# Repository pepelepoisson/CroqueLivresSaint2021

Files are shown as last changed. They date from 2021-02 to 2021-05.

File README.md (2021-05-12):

***
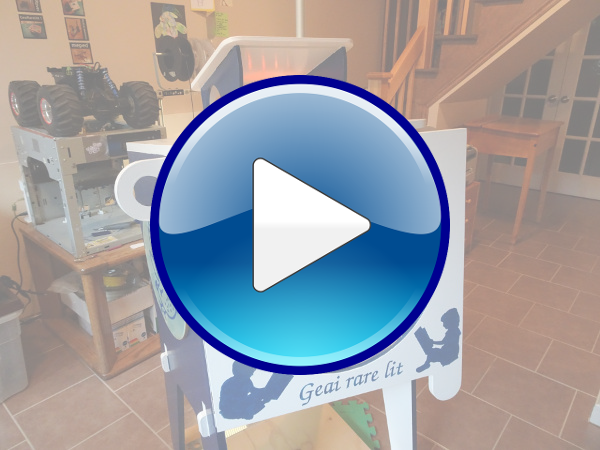
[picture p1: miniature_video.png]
Project video (https://youtu.be/Az-vB4r0-Qg)

***
This repo contains files about a project called GeaiRareLit. It is all about building a small ESP8266 brain for a little bookcase installed outside of my local school. The device is solar powered and drives WS2812B leds + epaper when door is opened. ePaper is used to display an inspiring sentence from a famous author. Users passing by the bookself get the chance to read the sentence even tough they have no book to give or take. All project details are available on the [project page](http://www.chezpapietmamie.com/pcube/uncategorized/geairarelit/)
***
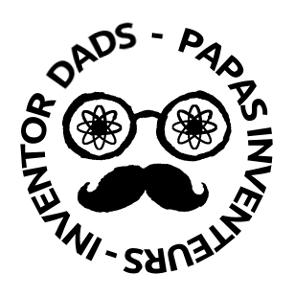
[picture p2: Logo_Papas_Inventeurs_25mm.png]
Inventor Dads logo


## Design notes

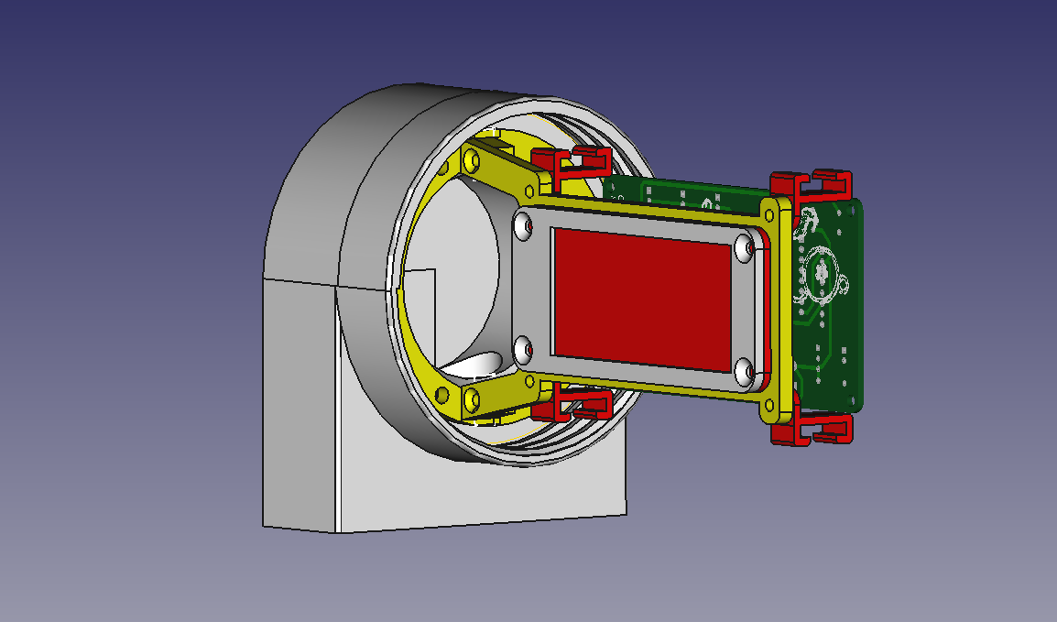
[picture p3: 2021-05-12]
CAD/concept2-3.png

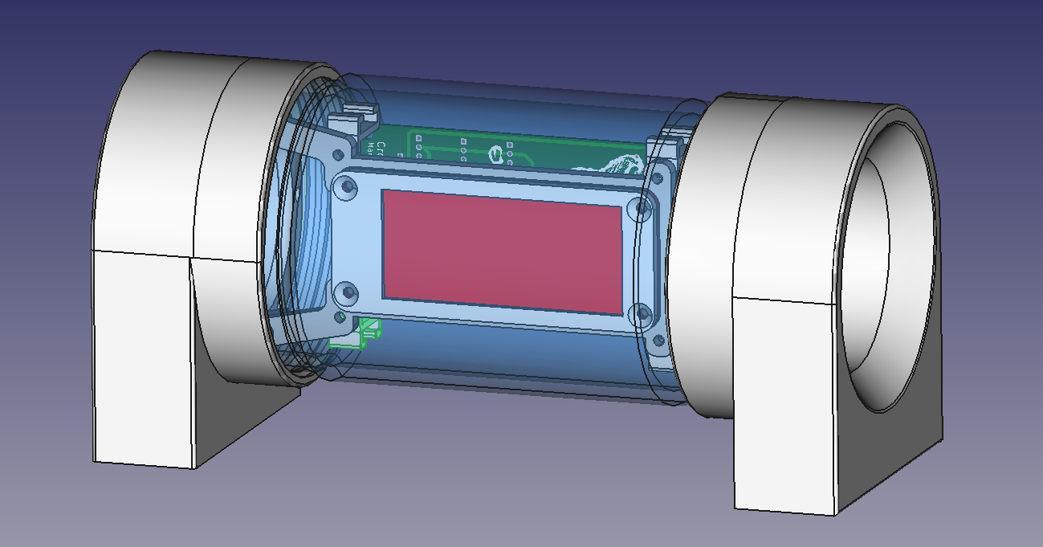
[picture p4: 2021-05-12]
CAD/concept2-1.png

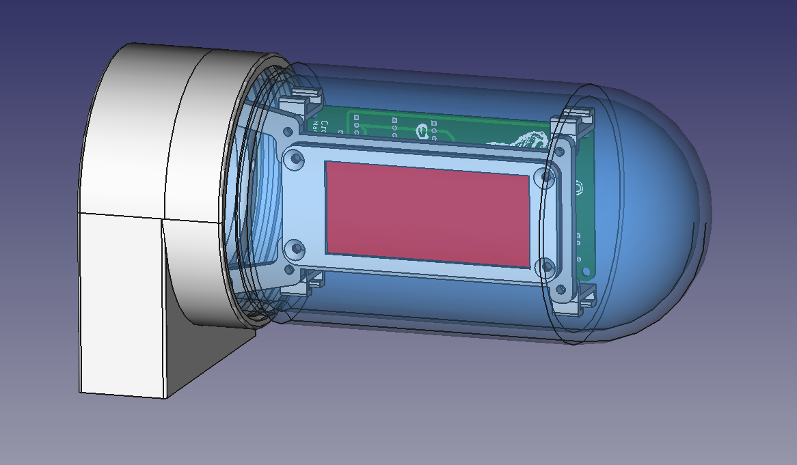
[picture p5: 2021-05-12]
CAD/concept2-2.png

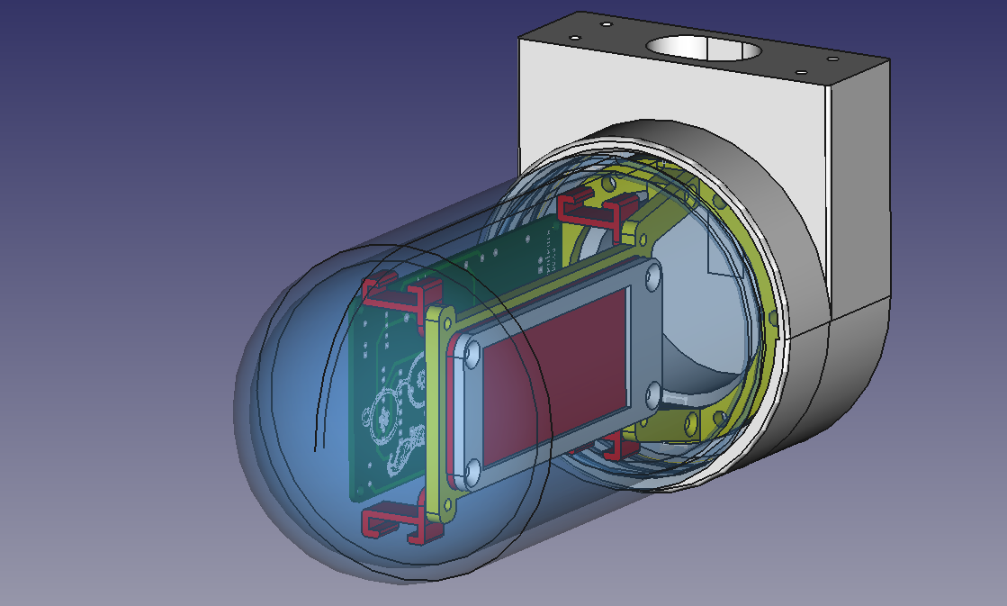
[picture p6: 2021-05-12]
CAD/concept2-4.png

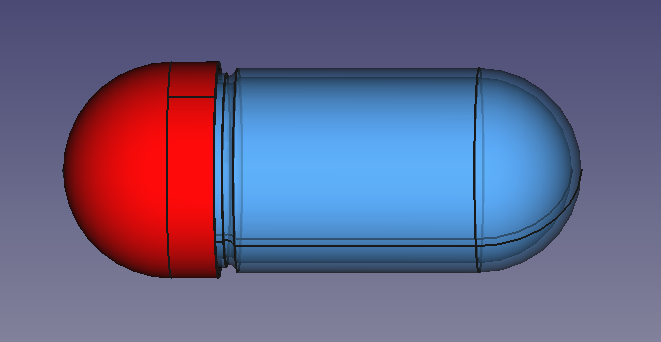
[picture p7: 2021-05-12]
CAD/concept1.png

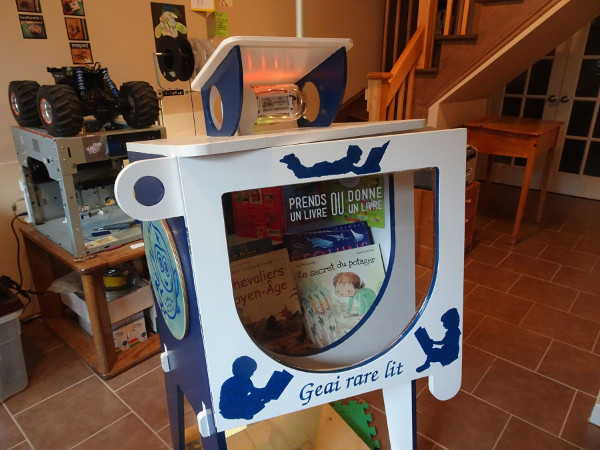
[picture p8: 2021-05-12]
miniature.png

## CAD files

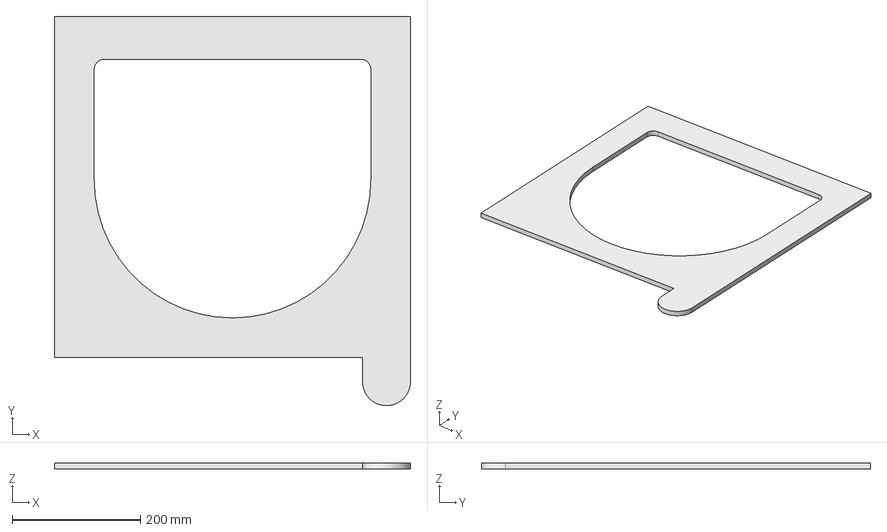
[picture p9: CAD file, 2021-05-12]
CAD/CNC/porte.FCStd
556.0 x 608.0 x 10.0 mm

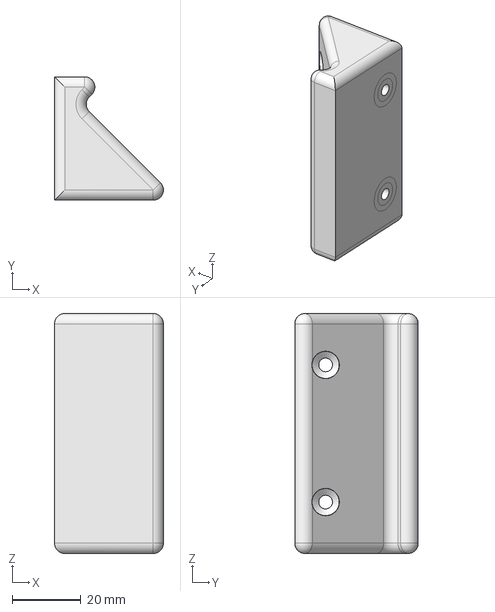
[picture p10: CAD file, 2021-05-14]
CAD/Poignée_V1.FCStd
31.8 x 36.0 x 70.0 mm

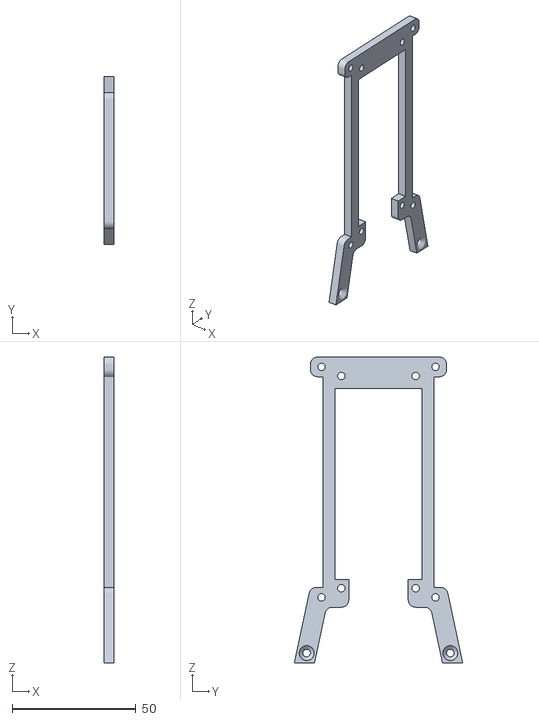
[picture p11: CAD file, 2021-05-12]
CAD/CrocSaintGerard_V5-support_plaque_ecran_V1.stl
4.00 x 68.0 x 123.5

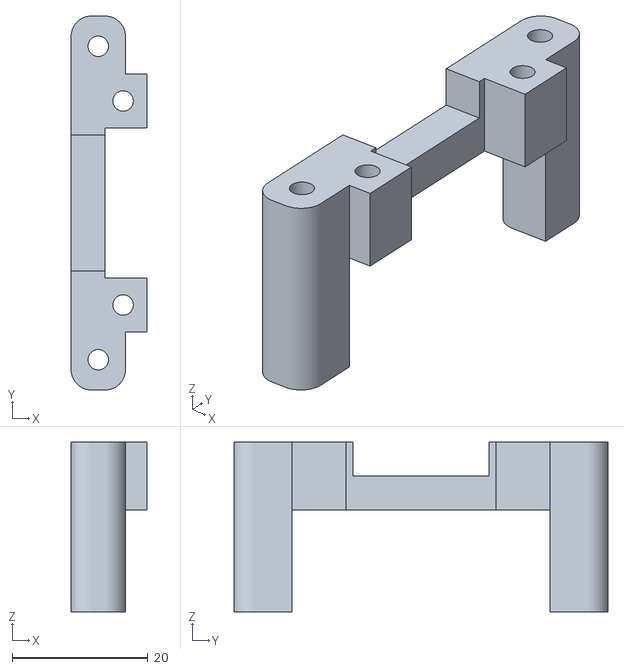
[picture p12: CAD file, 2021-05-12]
CAD/Montage_ecran_PCB_V2.stl
11.2 x 55.0 x 25.0

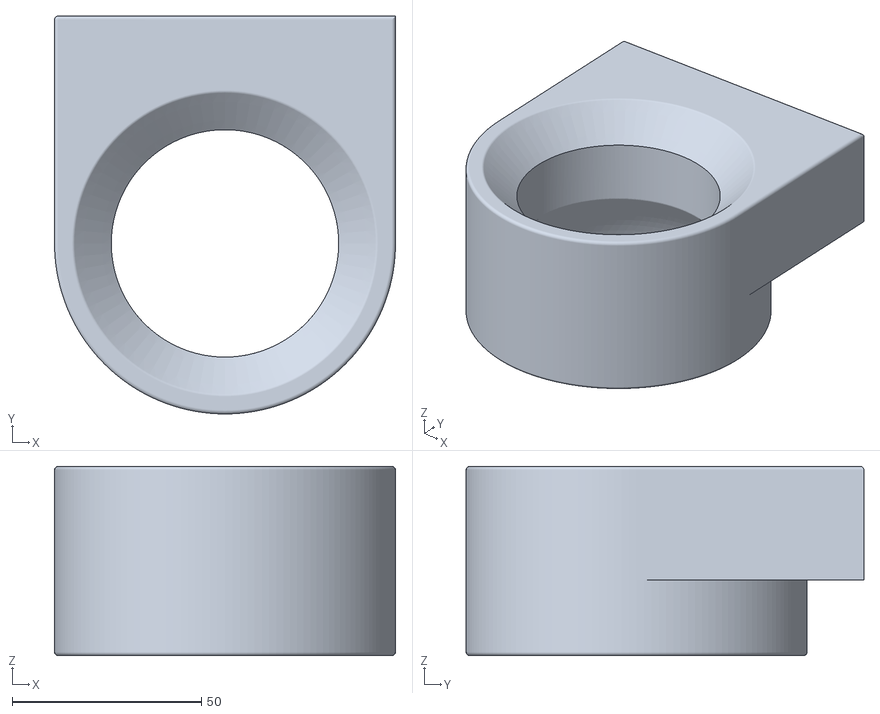
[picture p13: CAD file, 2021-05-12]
CAD/CrocSaintGerard_V4-tete_V1.stl
90.0 x 105.0 x 50.0

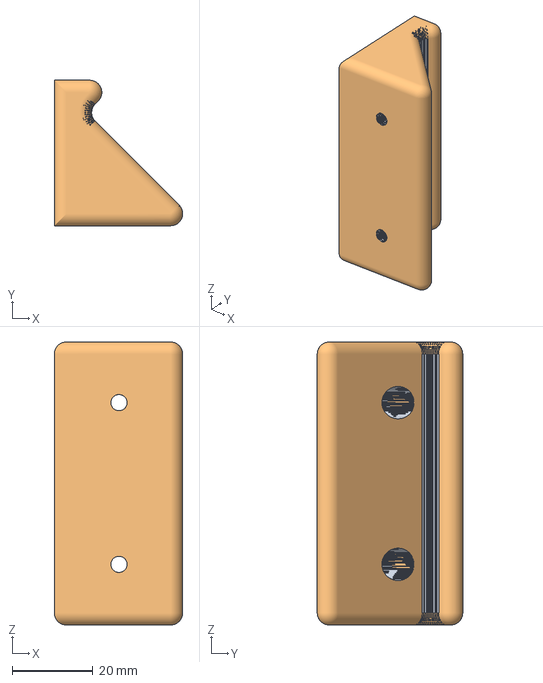
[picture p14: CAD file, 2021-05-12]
CAD/Butée_V1.FCStd
31.8 x 36.0 x 70.0 mm
Poignée
Poignée (Meshed)

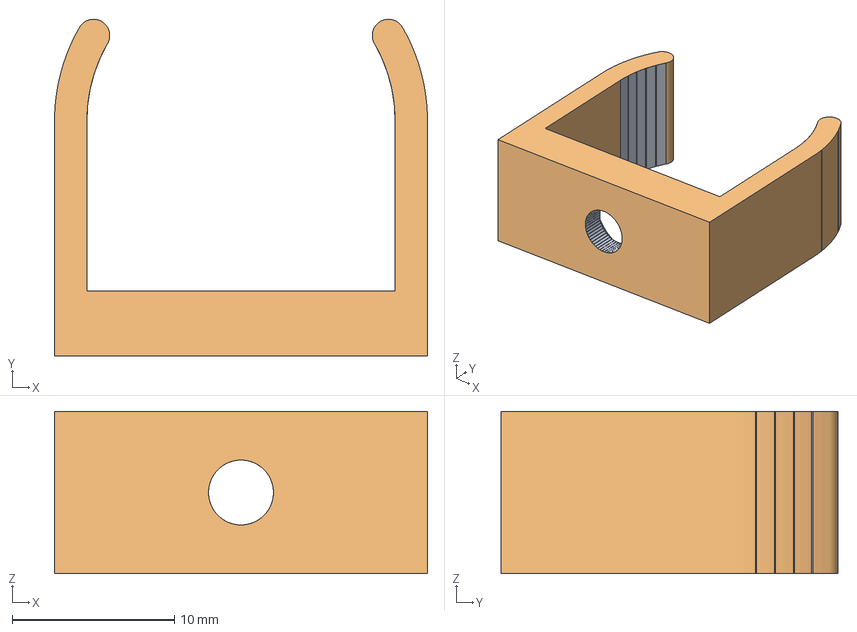
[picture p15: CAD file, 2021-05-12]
CAD/Support_batterie_V1.FCStd
23.0 x 20.8 x 10.0 mm
Body (Meshed)

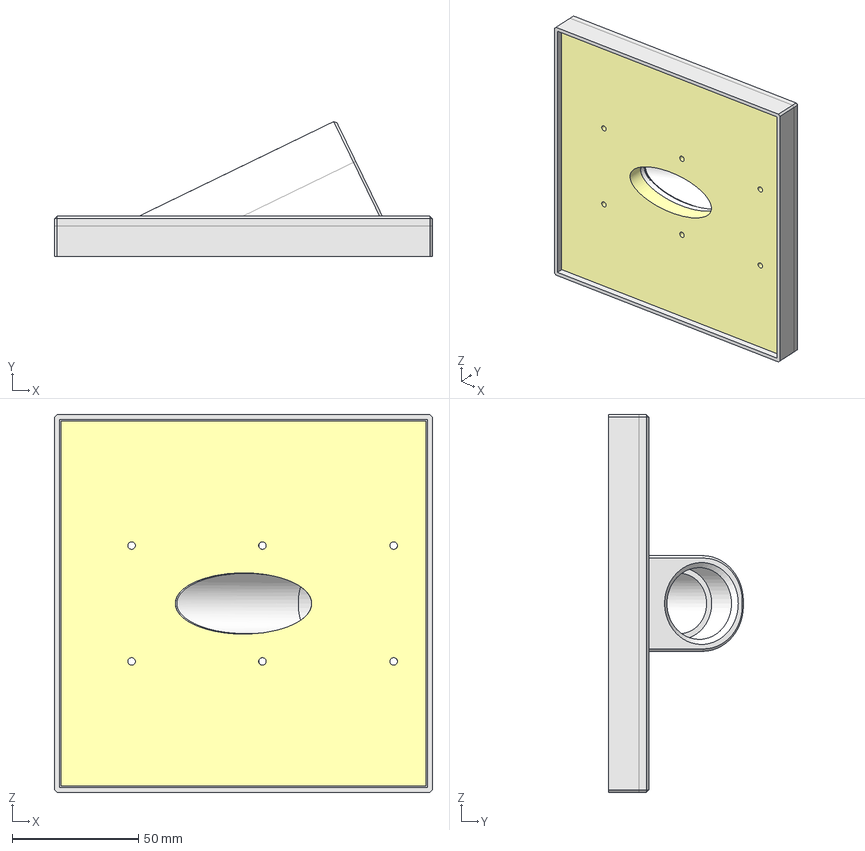
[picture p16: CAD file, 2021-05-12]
CAD/support_panneau_solaire_haut.FCStd
150.0 x 53.5 x 150.0 mm
fixation_mat
Contour
base_carree

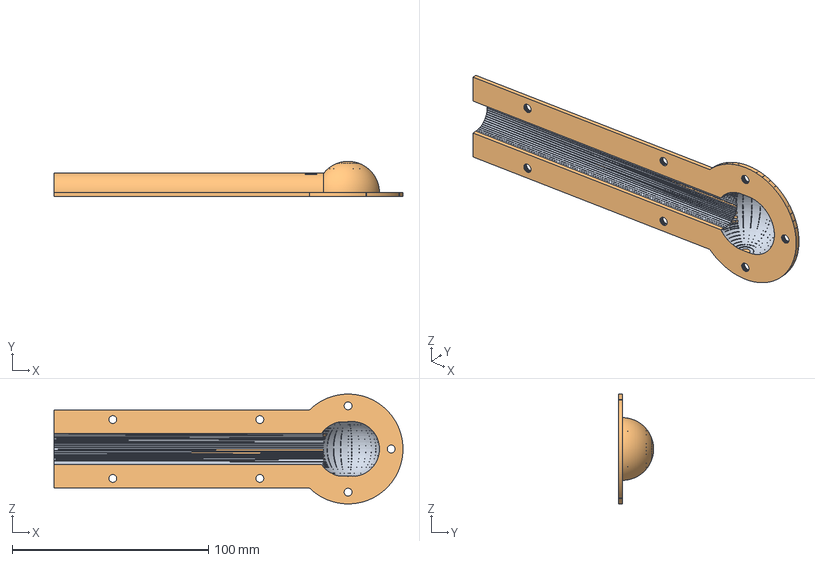
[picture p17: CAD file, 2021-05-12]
CAD/cache_fils_V1.FCStd
178.0 x 18.0 x 56.0 mm
Body (Meshed)

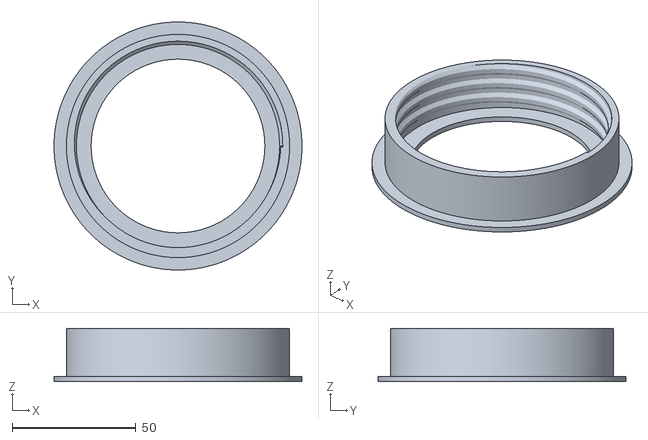
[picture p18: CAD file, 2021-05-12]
CAD/Test_base_vis_V1.stl
100.0 x 100.0 x 21.5

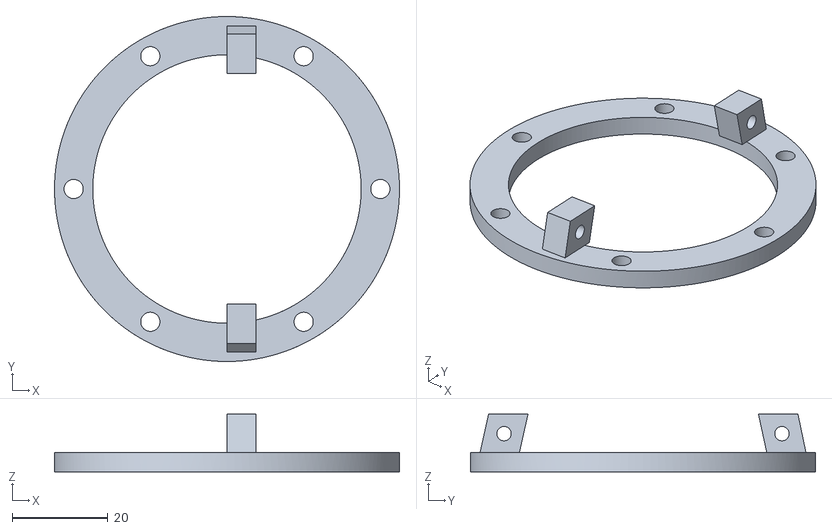
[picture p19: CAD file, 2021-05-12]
CAD/CrocSaintGerard_V5-fixation_support_plaque_ecran_V1.stl
72.0 x 72.0 x 12.0

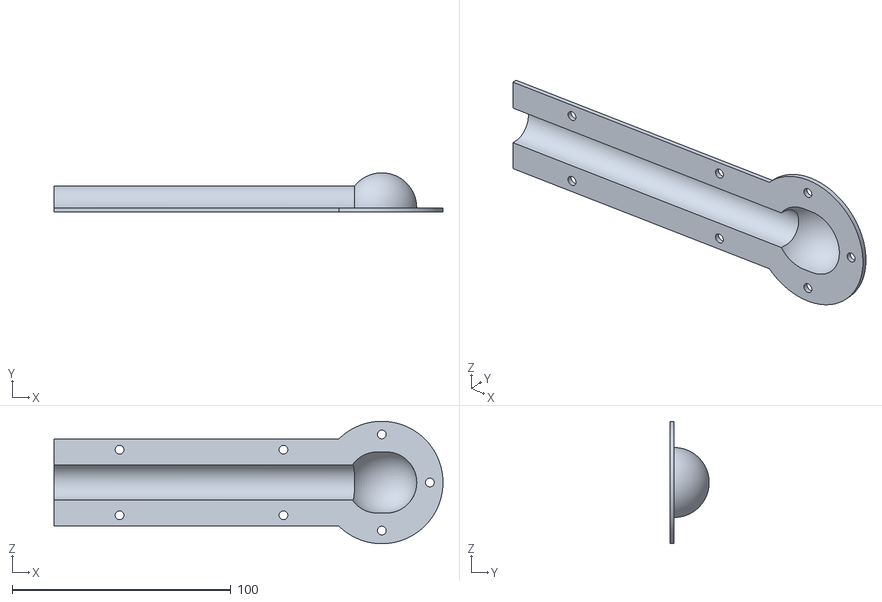
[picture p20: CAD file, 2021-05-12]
CAD/cache_fils_V1_V1.stl
178.0 x 18.0 x 56.0

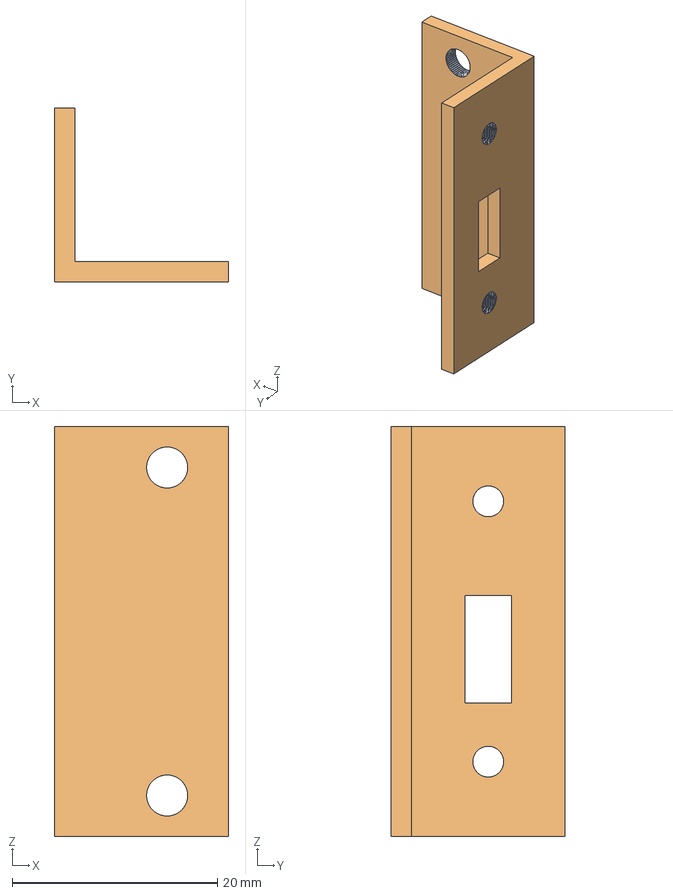
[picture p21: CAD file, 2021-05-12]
CAD/Support_interrupteur_V1.FCStd
17.0 x 17.0 x 40.0 mm
Support_unterrupteur
Support_unterrupteur (Meshed)

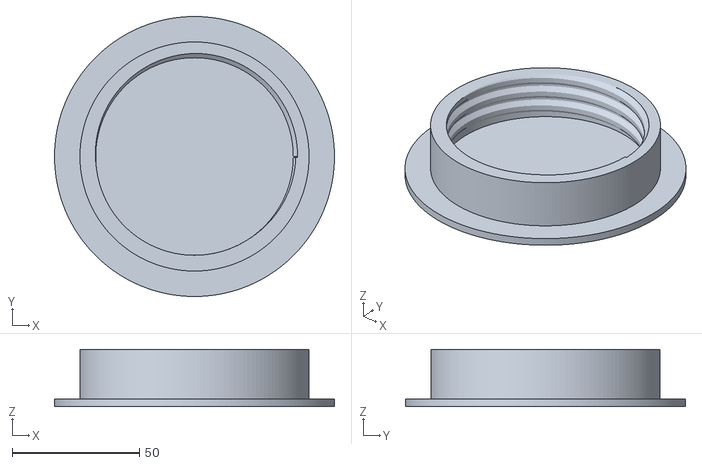
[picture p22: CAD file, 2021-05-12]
CAD/Vis-Body (Meshed).stl
110.0 x 110.0 x 22.5

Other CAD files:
CAD/Assemblage_PCB_ecran.FCStd
CAD/CrocSaintGerard.FCStd
CAD/Poignée_V1_V1.stl
CAD/CrocSaintGerard_V6.FCStd
CAD/Butée_V1.stl
CAD/CrocSaintGerard_V2.FCStd
CAD/CrocSaintGerard_V3-fixation_enceinte_verre_V1.stl
CAD/CrocSaintGerard_V3-tete_V1.stl
CAD/CrocSaintGerard_V3.FCStd
CAD/CrocSaintGerard_V4.FCStd
CAD/CrocSaintGerard_V5-attache_leds_V1.stl
CAD/CrocSaintGerard_V5.FCStd
CAD/Montage_ecran_PCB_V1.stl
CAD/Support_batterie_V1.stl
CAD/Support_interrupteur_V1.stl
CAD/Vis.FCStd
CAD/support_panneau_solaire_haut_Contour_V1.stl
CAD/support_panneau_solaire_haut_V1.stl

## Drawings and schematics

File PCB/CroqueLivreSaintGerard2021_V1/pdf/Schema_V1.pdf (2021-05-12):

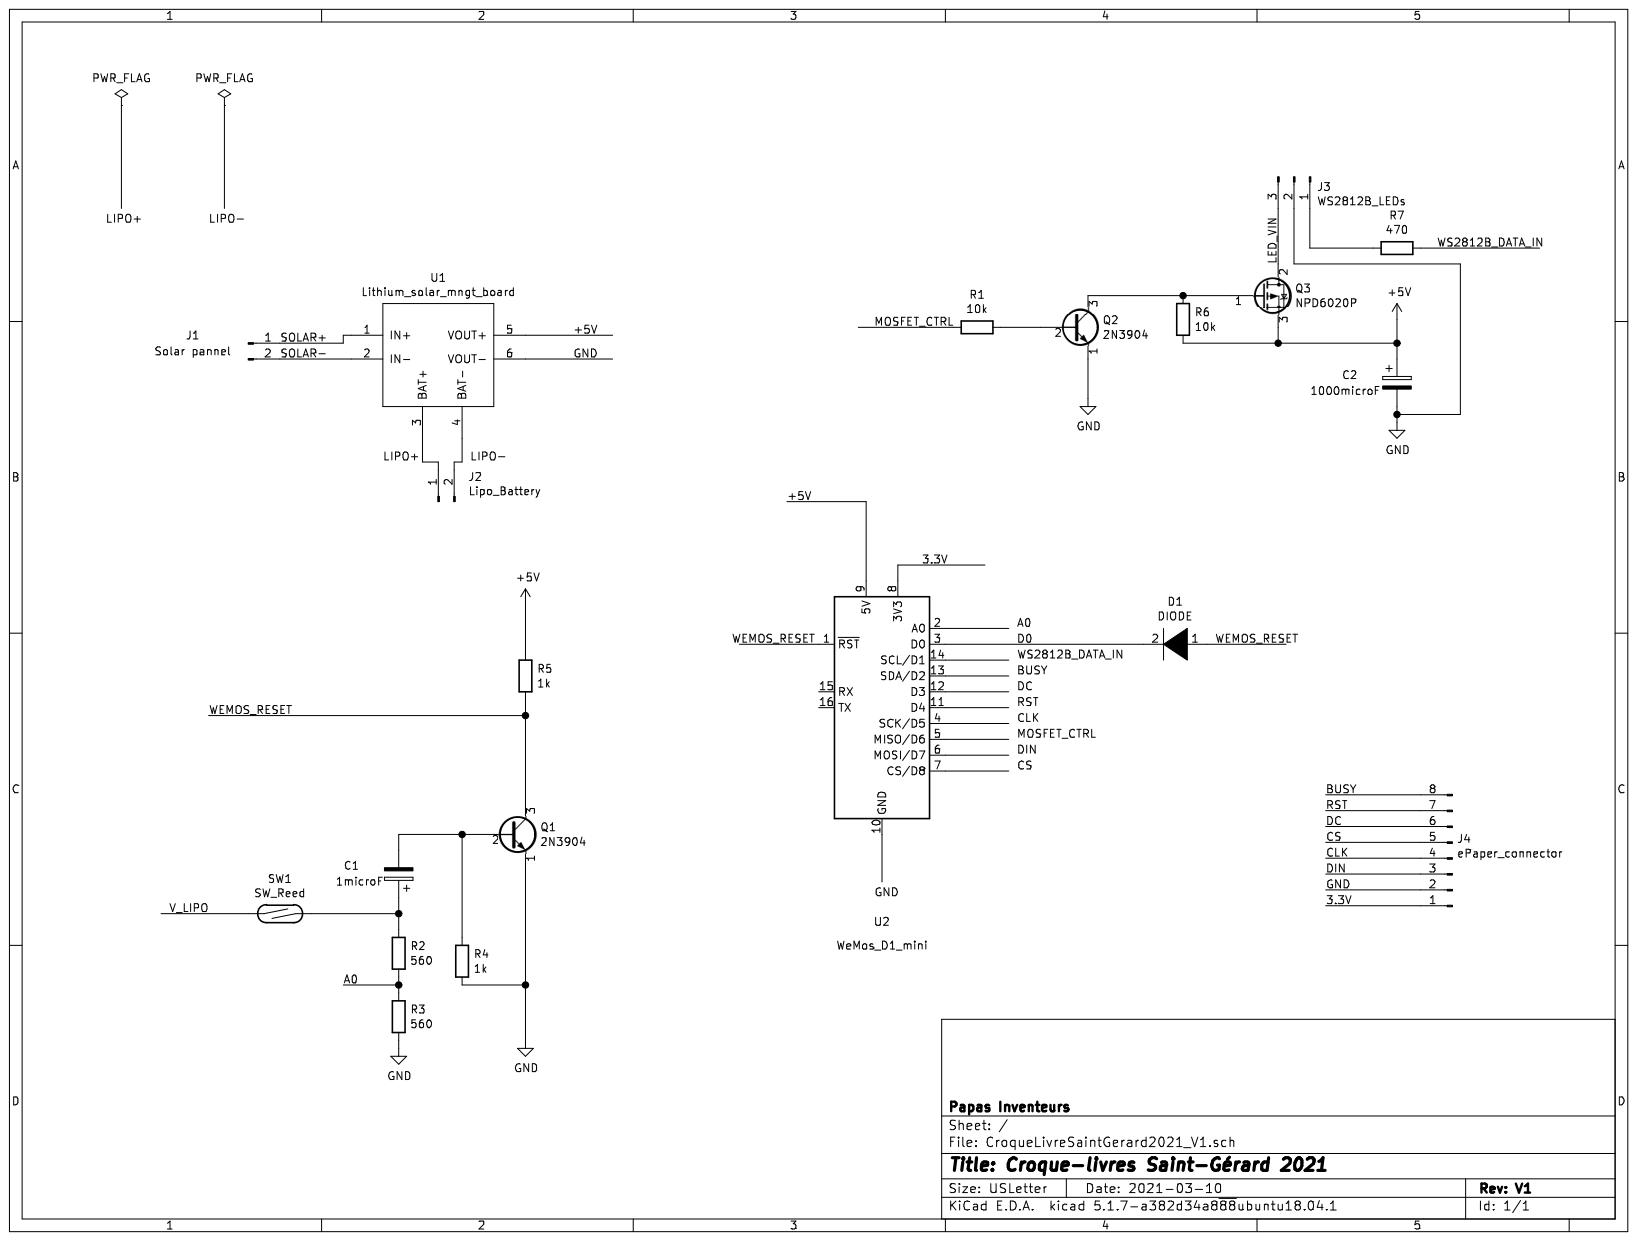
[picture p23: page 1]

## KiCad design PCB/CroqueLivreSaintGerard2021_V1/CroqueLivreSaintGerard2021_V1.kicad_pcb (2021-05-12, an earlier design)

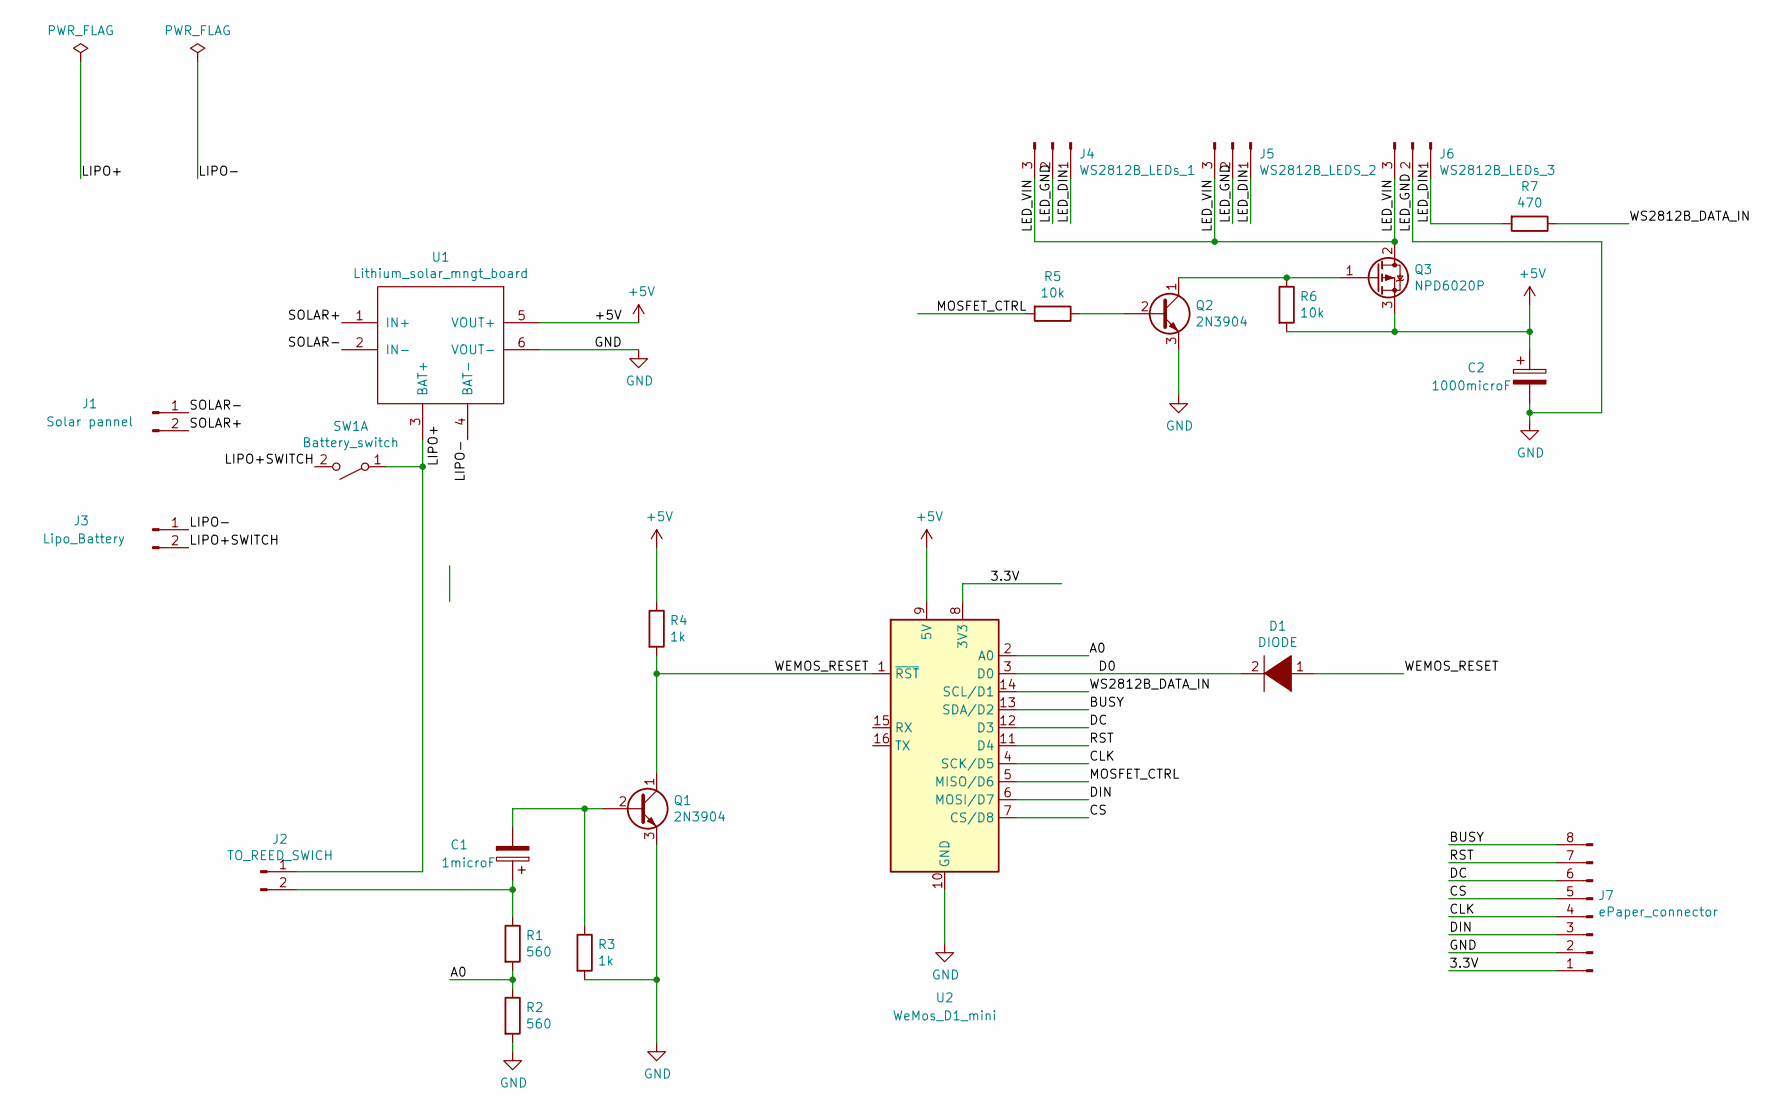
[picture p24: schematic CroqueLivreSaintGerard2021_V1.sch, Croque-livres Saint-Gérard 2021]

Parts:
C1: 1microF; CP_Radial_D6.3mm_P2.50mm
C2: 1000microF; Edge_CP_Radial_D12.5mm_P5.00mm
D1: DIODE; D_DO-41_SOD81_P10.16mm_Horizontal
J1: Solar pannel; JST_EH_S2B-EH_1x02_P2.50mm_Horizontal
J2: TO_REED_SWICH; PinHeader_1x02_P2.54mm_Horizontal
J3: Lipo_Battery; JST_EH_S2B-EH_1x02_P2.50mm_Horizontal
J4: WS2812B_LEDs_1; PinHeader_1x03_P2.54mm_Vertical
J5: WS2812B_LEDS_2; PinHeader_1x03_P2.54mm_Vertical
J6: WS2812B_LEDs_3; PinHeader_1x03_P2.54mm_Vertical
J7: ePaper_connector; PinSocket_1x08_P2.54mm_Horizontal
Q1, Q2: 2N3904; TO-92L_Inline_Wide
Q3: NPD6020P; TO-220-3_Horizontal_TabDown
R1, R2: 560; R_Axial_DIN0207_L6.3mm_D2.5mm_P10.16mm_Horizontal
R3, R4: 1k; R_Axial_DIN0207_L6.3mm_D2.5mm_P10.16mm_Horizontal
R5, R6: 10k; R_Axial_DIN0207_L6.3mm_D2.5mm_P10.16mm_Horizontal
R7: 470; R_Axial_DIN0207_L6.3mm_D2.5mm_P10.16mm_Horizontal
SW1: Battery_switch; SW_Slide_1P2T_CK_OS102011MS2Q
U1: Lithium_solar_mngt_board
U2: WeMos_D1_mini; WEMOS_D1_mini_light

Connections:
+5V: C2.1, Q3.3 (S), R4.1, R6.2, U1.5 (VOUT+), U2.9 (5V)
/3.3V: J7.1, U2.8 (3V3)
/A0: R1.2, R2.1, U2.2 (A0)
/BUSY: J7.8, U2.13 (SDA/D2)
/CLK: J7.4, U2.4 (SCK/D5)
/CS: J7.5, U2.7 (CS/D8)
/D0: D1.2 (A), U2.3 (D0)
/DC: J7.6, U2.12 (D3)
/DIN: J7.3, U2.6 (MOSI/D7)
/LED_DIN: J4.1, J5.1, J6.1, R7.2
/LED_VIN: J4.3, J5.3, J6.3, Q3.2 (D)
/LIPO+SWITCH: J3.2, SW1.2 (B); also elsewhere on the board
/LIPO-: J3.1, U1.4 (BAT-); also elsewhere on the board
/MOSFET_CTRL: R5.2, U2.5 (MISO/D6)
/RST: J7.7, U2.11 (D4)
/SOLAR+: J1.2, U1.1 (IN+); also elsewhere on the board
/SOLAR-: J1.1, U1.2 (IN-); also elsewhere on the board
/WEMOS_RESET: D1.1 (K), Q1.1 (C), R4.2, U2.1 (~RST)
/WS2812B_DATA_IN: R7.1, U2.14 (SCL/D1)
GND: C2.2, J4.2, J5.2, J6.2, J7.2, Q1.3 (E), Q2.3 (E), R2.2, R3.2, U1.6 (VOUT-), U2.10 (GND)
unnamed: C1.1, J2.2, R1.1
unnamed: C1.2, Q1.2 (B), R3.1
unnamed: J2.1, SW1.1 (A), U1.3 (BAT+)
unnamed: Q2.1 (C), Q3.1 (G), R6.1
unnamed: Q2.2 (B), R5.1

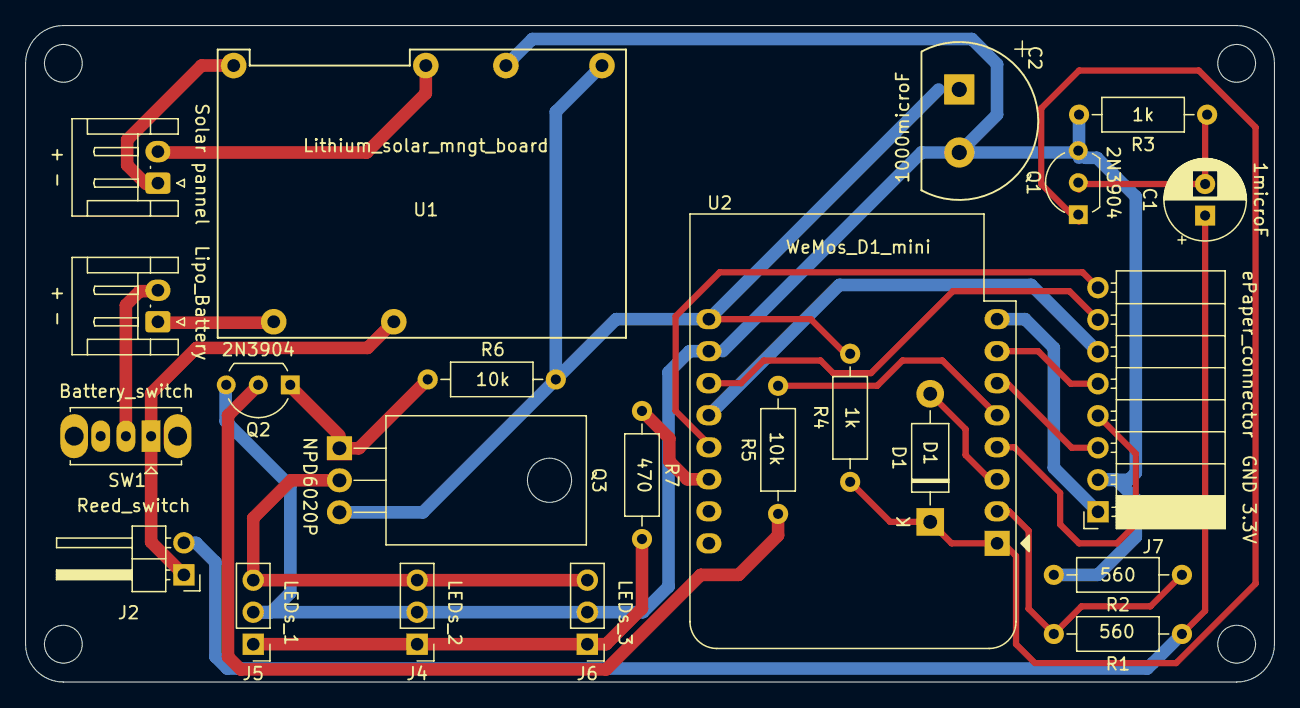
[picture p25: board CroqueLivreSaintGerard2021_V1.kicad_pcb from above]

Board: 2 copper layers, 99.1 x 52.1 mm, 24 parts (1 on the bottom side), 25 nets.

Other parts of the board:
+ -: Lipo_Battery; JST_EH_S2B-EH_1x02_P2.50mm_Horizontal
+ -#2: Solar pannel; JST_EH_S2B-EH_1x02_P2.50mm_Horizontal
LOGO_papas_inventeurs_et_jeunes: LOGO_papas_inventeurs_et_jeunes (72x48mm)

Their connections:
/LIPO+SWITCH: + -.2; also elsewhere on the board
/LIPO-: + -.1; also elsewhere on the board
/SOLAR+: + -#2.2; also elsewhere on the board
/SOLAR-: + -#2.1; also elsewhere on the board

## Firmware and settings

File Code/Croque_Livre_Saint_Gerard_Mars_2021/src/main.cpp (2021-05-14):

// To do:
// Change deco leds to be displayed on 9 and 30 LEDs strips
// Wifi mode: only start wifi access is door is closed less than 3 seconds after opening
// Fix citation counter disply and avoid showing a blank screen at the end of the sequence

// Done - now in trial mode:
// Code to handle access point and station mode wifi
// Store number of code execution in persistent memory
// Handle new epaper type
// Handle reading different text content at every execution
// Improve wake-up hardware and detect when door is open
// Control duration of LED animatins and sleep start based on door status
// Must handle errors when reading log file gives no valid number
// Allow use of international characters when printing text (accents)
// Measure battery level
// Add end of line characters as needed to prevent words from cutting at the end of lines when text is displayed on epaper.

// Main examples used to build this secondes
// Basic SPIFFS write/read example: https://github.com/G6EJD/SPIFFS-Examples/blob/master/ESP8266_SPIFFS_Example.ino
// Uploading a file to SPIFFS from browser: https://www.esp8266.com/viewtopic.php?t=5779&start=10#

// Wonderfull online true type to gfx fonts conversion tool: https://rop.nl/truetype2gfx/
// Wonderfull online tool to edit fonts: https://tchapi.github.io/Adafruit-GFX-Font-Customiser/

#include <Arduino.h>
#include <GxEPD2.h>
#include <Adafruit_GFX.h>
#include <Adafruit_I2CDevice.h>
#include <ESP8266WiFi.h>
#include <WiFiClient.h>
#include <ESP8266WebServer.h>
#include <Adafruit_NeoPixel.h>
#include <FS.h> //spiff file system
#include <ArduinoJson.h>

#define ARRAY_SIZE(A) (sizeof(A) / sizeof((A)[0]))
#define LOW_BRIGHTNESS          20
#define FRAMES_PER_SECOND   60 // 125 frames/sec <=> 8 milli/frame
#define NUM_LEDS  30
#define DATA_PIN    5
#define MOSFET_GATE  12
#define LED_ANIMATIONS_DURATION 60000 // Duration of LED animations (Milliseconds)

Adafruit_NeoPixel strip = Adafruit_NeoPixel(NUM_LEDS, DATA_PIN, NEO_GRB + NEO_KHZ800);
uint8_t gCurrentPatternNumber = 0; // Index number of which pattern is current
uint16_t brightness=LOW_BRIGHTNESS;
long start_time=0;
int updated_code_run_counter=0;
int updated_current_citation=0;
int number_of_citations=0;
bool doorOpen=false;
bool citations_file_exists=false;
String wifi_status = "Disconnected";

const int analogInPin = A0;  // ESP8266 Analog Pin ADC0 = A0
int sensorValue = 0;  // value read from the ADC0
float batteryVoltage=0;
#define batteryVoltageCalibration 165.45

#define ENABLE_GxEPD2_GFX 1

#include <GxEPD2_BW.h>
#include <GxEPD2_3C.h>
//#include <Fonts/FreeMonoBold9pt7b.h>
#include <ModifiedFreeMonoBold9pt7b.h>
#include <Fonts/FreeMonoBold24pt7b.h>
//#include "Audiowide_Regular9pt7b.h"
//#include <Fonts/TomThumb.h>
//#include "bitmaps/Bitmaps200x200.h" // 1.54" b/w
#include "bitmaps/Bitmaps128x296.h" // 2.9"  b/w
//#include "project_bitmaps.h"

#define RST_PIN 0 // D3(0)
#define CS_1 SS // CS = D8(15)
#define BUSY_H_x 4 // BUSY = D2(4)

GxEPD2_BW<GxEPD2_290_M06, GxEPD2_290_M06::HEIGHT> display1(GxEPD2_290_M06(/*CS=*/ CS_1, /*DC=D3*/ 0, /*RST=*/ -1, /*BUSY=*/ BUSY_H_x)); // GDEW029M06

char* mySsid = "croque-livre";
// Type your own password
char* myPassword = "*******";
// Type your own IP address and gateway - This not the address in use on project ;-)
IPAddress local_ip(192,168,168,168);
IPAddress gateway(192,168,168,1);
IPAddress netmask(255,255,255,0);

char webpage[] PROGMEM = R"=====(
<html>
<meta charset="UTF-8">
<head>
</head>
<body>
  <form>
  <h1 style="font-size:60px;color:blue;" title="Croque-Livres">Croque-Livres Saint-Gérard</h1>
    <fieldset>
    <legend style="color:blue;">Paramètres pour la connexion à un réseau WiFi existant:</legend>
      <div>
        <label for="ssid">SSID</label>
        <input value="" id="ssid" placeholder="SSID">
      </div>
      <div>
        <label for="password">PASSWORD</label>
        <input type="password" value="" id="password" placeholder="PASSWORD">
      </div>
      <div>
        <button class="primary" id="savebtn" type="button" onclick="myFunction()">SAVE</button>
      </div>
    </fieldset>
  </form>
  <form method='POST' action='/update' enctype='multipart/form-data'>
    <fieldset>
    <legend style="color:blue;">Mise à jour du fichier des citations:</legend>
      <input type='file' name='update'>
      <input type='submit' value='Update'>
    </fieldset>
  </form>
</body>
<script>
function myFunction()
{
  console.log("button was clicked!");

  var ssid = document.getElementById("ssid").value;
  var password = document.getElementById("password").value;
  var data = {ssid:ssid, password:password};

  var xhr = new XMLHttpRequest();
  var url = "/settings";

  xhr.onreadystatechange = function() {
    if (this.readyState == 4 && this.status == 200) {
      // Typical action to be performed when the document is ready:
      if(xhr.responseText != null){
        console.log(xhr.responseText);
      }
    }
  };

  xhr.open("POST", url, true);
  xhr.send(JSON.stringify(data));
};

</script>
</html>
)=====";

char current_filename [] = "/data/citations.txt";

String filename;
ESP8266WebServer server(80);
//holds the current upload
File UploadFile;

void updateSPIFFS()
{
  const char * _code_run_counter = "", *_current_citation = "";
  if(SPIFFS.exists("/log.json")){
    Serial.println("Found /log.json file");
    File logFile = SPIFFS.open("/log.json", "r");
    if(logFile){
      size_t size = logFile.size();
      std::unique_ptr<char[]> buf(new char[size]);
      logFile.readBytes(buf.get(), size);
      logFile.close();

      DynamicJsonBuffer logjsonBuffer;
      JsonObject& logjObject = logjsonBuffer.parseObject(buf.get());
      if(logjObject.success())
      {
        _code_run_counter = logjObject["code_run_counter"];
        _current_citation = logjObject["current_citation"];
        //Serial.print("code_run_counter: "); Serial.print(_code_run_counter); Serial.print(" current_citation: ");Serial.println(_current_citation);
      }
    }
  }
  else {_code_run_counter = "1";  _current_citation = "1";}

  // Convert counters from char to integer then add one.
  updated_code_run_counter=atoi(_code_run_counter);
  updated_current_citation=atoi(_current_citation);

  String logData = "{code_run_counter:"+String(updated_code_run_counter)+", current_citation:"+String(updated_current_citation)+", number_of_citations:"+String(number_of_citations)+"}";
  //String logData = "{code_run_counter:10, current_citation:5}";
  DynamicJsonBuffer logjBuffer;
  JsonObject& logjObject = logjBuffer.parseObject(logData);
  File logFile = SPIFFS.open("/log.json", "w");
  logjObject.printTo(logFile);
  logFile.close();
  Serial.println(logData);

}

void FileRead() {
  String NewLine;
  int number_of_lines=0;
  Serial.println("reading...");
  Serial.println("/data/" + filename);

  if (SPIFFS.exists("/data/" + filename)) {
    File FileRead = SPIFFS.open("/data/" + filename, "r");
    Serial.print("output: ");
    Serial.println();
    while (FileRead.available() > 0) {
      char In = FileRead.read();
      NewLine += In;

      if (In == '\n') {
        Serial.print(NewLine);
        NewLine = "";
        number_of_lines=number_of_lines+1;
      }
    }

    FileRead.close();
    Serial.print("Number of lines in file: "); Serial.println(number_of_lines);
    if (filename=="citations.txt"){
      number_of_citations=number_of_lines;
      updateSPIFFS();
    }
  }
}

//format bytes - Used to format file size when displaying SPIFFS file content
String formatBytes(size_t bytes){
  if (bytes < 1024){
    return String(bytes)+"B";
  } else if(bytes < (1024 * 1024)){
    return String(bytes/1024.0)+"KB";
  } else if(bytes < (1024 * 1024 * 1024)){
    return String(bytes/1024.0/1024.0)+"MB";
  } else {
    return String(bytes/1024.0/1024.0/1024.0)+"GB";
  }
}

String formatMessage(String message)
{
  // Add end line characters to avoid breaking words at end of lines
  uint16_t k=26,startpos=0, line=1;
  int messageLength=message.length();
  Serial.println(message);
  Serial.println(messageLength);
  char Buf[messageLength+1]; // Char array used to manipulate string content by position
  message.toCharArray(Buf, messageLength+1);  // Store sting content in a char array.

  for(line; line<8; line++){
    Serial.print("line: "); Serial.println(line);
    if (messageLength-startpos>26){  // Code to run only if remaining char array length exceeds maximum size for one line with this font.
      k=26;
      Serial.print("startpos:"); Serial.println(startpos);
      for (k; k>1;k--){   // Starting at the end of line, walk back until a space is found = begining of last word.
        Serial.println(Buf[k]);
        if (Buf[startpos+k]==' '){  // Replace space with line break and update counter of next line start.
          Buf[startpos+k]='\n';
          startpos=startpos+k+1;
          break;
        }
      }
    }
  }

  message=Buf;
  return message;
}

void print_string(GxEPD2_GFX& display, String message)
{
  display.setRotation(3);
  display.setFont(&FreeMonoBold9pt7b);
  //display.setFont(&FreeSerifItalic9pt7b);
  //display.setFont(&Audiowide_Regular9pt7b);
  //display.setFont(&TomThumb);
  display.setTextColor(GxEPD_BLACK);
  //uint16_t x = (display.width() - 160) / 2;
  //uint16_t y = display.height() / 2;
  display.setFullWindow();
  display.firstPage();
  do
  {
    display.fillScreen(GxEPD_WHITE);
    //display.setCursor(x, y);
    display.setCursor(0, 10);
    display.println(message);
  }
  while (display.nextPage());
}

void drawBitmaps128x296(GxEPD2_GFX& display){
  const unsigned char* bitmaps[] = {AventuriersSaintGerard,PapasInventeursEtJeunes_128x296};
  bool m = display.mirror(true);
  for (uint16_t i = 0; i < sizeof(bitmaps) / sizeof(char*); i++){
    display.firstPage();
    do {
      Serial.println(i);
      display.fillScreen(GxEPD_WHITE);
      display.drawInvertedBitmap(0, 0, bitmaps[i], display.epd2.WIDTH, display.epd2.HEIGHT, GxEPD_BLACK);
    }
    while (display.nextPage());
    delay(2000);
  }
  display.mirror(m);
}


void drawBitmaps(GxEPD2_GFX& display){
  display.setFullWindow();
  display.setRotation(0);
  drawBitmaps128x296(display);
}

void displayDashboard(GxEPD2_GFX& display, int code_run_counter, int current_citation, int number_of_citations, float batteryVoltage){
  //display.fillScreen(GxEPD_WHITE);
  //display.fillRect(0, 0, 100, 100, GxEPD_BLACK);
  display.setRotation(3);
  display.setTextColor(GxEPD_BLACK);
  display.setFullWindow();
  display.firstPage();
  do
  {
    display.fillScreen(GxEPD_WHITE);
    // Draw boxes with round corners
    display.drawRoundRect(2, 2, 143, 124, 8, GxEPD_BLACK);
    display.drawRoundRect(150, 2, 146, 124, 8, GxEPD_BLACK);

    display.setFont(&FreeMonoBold9pt7b);
    display.setCursor(10, 20);
    display.print("Ex}cutions: ");
    display.setFont(&FreeMonoBold24pt7b);
    display.setCursor(20, 55);
    display.println(String(code_run_counter));

    display.setFont(&FreeMonoBold9pt7b);
    display.setCursor(10, 75);
    display.print("Citation: ");
    display.setFont(&FreeMonoBold24pt7b);
    display.setCursor(20, 115);
    display.println(String(current_citation%number_of_citations));

    display.setFont(&FreeMonoBold9pt7b);
    display.setCursor(155, 20);
    display.print("Batterie(V):  ");
    display.setFont(&FreeMonoBold24pt7b);
    display.setCursor(165, 75);
    display.print(String(batteryVoltage));
    //display.println("V");
  }
  while (display.nextPage());
}


// Input a value 0 to 255 to get a color value.
// The colours are a transition r - g - b - back to r.
uint32_t Wheel(byte WheelPos) {
  WheelPos = 255 - WheelPos;
  if(WheelPos < 85) {
    return strip.Color(255 - WheelPos * 3, 0, WheelPos * 3);
  }
  if(WheelPos < 170) {
    WheelPos -= 85;
    return strip.Color(0, WheelPos * 3, 255 - WheelPos * 3);
  }
  WheelPos -= 170;
  return strip.Color(WheelPos * 3, 255 - WheelPos * 3, 0);
}

// Fill the dots one after the other with a color
void colorWipe(uint32_t c) {
  for(uint16_t i=0; i<strip.numPixels(); i++) {
    strip.setPixelColor(i, c);
  }
  strip.show();
}

void colorTransientWipe(uint32_t c) {
  for(uint16_t i=0; i<strip.numPixels(); i++) {
    strip.setPixelColor(i, c);
    strip.show();
    delay(25);
  }
}

void rainbow() {
  uint16_t i, j;

  for(j=0; j<256; j++) {
    for(i=0; i<strip.numPixels(); i++) {
      strip.setPixelColor(i, Wheel((i+j) & 255));
    }
  }
}

// Slightly different, this makes the rainbow equally distributed throughout
void rainbowCycle() {
  uint16_t i, j;

  for(j=0; j<256; j++) {
    for(i=0; i< strip.numPixels(); i++) {
      strip.setPixelColor(i, Wheel(((i * 256 / strip.numPixels()) + j) & 255));
    }
  }
}


// List of patterns to cycle through.  Each is defined as a separate function below.
typedef void (*SimplePatternList[])();
SimplePatternList gPatterns = {rainbowCycle};
char* SimplePatternNames[]={"rainbowCycle" };

void nextPattern(){
  // add one to the current pattern number, and wrap around at the end
  gCurrentPatternNumber = (gCurrentPatternNumber + 1) % ARRAY_SIZE(gPatterns);
}

void LED(String pattern){

  if (pattern=="deco"){
    digitalWrite(MOSFET_GATE,HIGH);
    //gPatterns[gCurrentPatternNumber]();
    rainbowCycle();
    //colorWipe(strip.Color(0, 0, 255));
  }

  if (pattern=="off"){
    //for (int i = NUM_LEDS; i >=0; i--) {leds[i].nscale8(230);}
    digitalWrite(MOSFET_GATE,LOW);
  }

  // send the 'leds' array out to the actual LED strip
  strip.show();
  // insert a delay to keep the framerate modest
  delay(1000/FRAMES_PER_SECOND);
}

void wifiConnect()
{
  //reset networking
  WiFi.softAPdisconnect(true);
  WiFi.disconnect();
  delay(1000);
  //check for stored credentials

  if(SPIFFS.exists("/config.json")){
    Serial.println("Found /config.json file");
    const char * _ssid = "", *_pass = "";
    File configFile = SPIFFS.open("/config.json", "r");
    if(configFile){
      size_t size = configFile.size();
      std::unique_ptr<char[]> buf(new char[size]);
      configFile.readBytes(buf.get(), size);
      configFile.close();

      DynamicJsonBuffer jsonBuffer;
      JsonObject& jObject = jsonBuffer.parseObject(buf.get());
      if(jObject.success())
      {
        _ssid = jObject["ssid"];
        _pass = jObject["password"];
        //Serial.print(_ssid); Serial.println(_pass);
        WiFi.mode(WIFI_STA);
        WiFi.begin(_ssid, _pass);
        unsigned long startTime = millis();
        while (WiFi.status() != WL_CONNECTED)
        {
          delay(500);
          Serial.print(".");
          if ((unsigned long)(millis() - startTime) >= 10000) break;
        }
      }
    }
  }

  if (WiFi.status() != WL_CONNECTED)
  {
    WiFi.mode(WIFI_AP);
    WiFi.softAPConfig(local_ip, gateway, netmask);
    WiFi.softAP(mySsid, myPassword);
    Serial.println("Unable to connect to a known wifi network - Starting ESP as Access Point.");
    wifi_status="Access Point";
  }
  else {Serial.println(""); Serial.println("ESP now connected in STAtion mode to known network.");wifi_status = "Station";}
  //Serial.println("");
  Serial.print("IP Address: ");
  Serial.println(WiFi.localIP());
  //WiFi.printDiag(Serial);

}

void handleSettingsUpdate()
{
  String data = server.arg("plain");
  DynamicJsonBuffer jBuffer;
  JsonObject& jObject = jBuffer.parseObject(data);

  File configFile = SPIFFS.open("/config.json", "w");
  jObject.printTo(configFile);
  configFile.close();

  server.send(200, "application/json", "{\"status\" : \"ok\"}");
  delay(500);

  wifiConnect();
}
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
void loop()
{
  server.handleClient();
  delay(1);

  LED("deco");
  // read the analog in value
  sensorValue = analogRead(analogInPin);

  if (sensorValue>100){doorOpen=true;}
  else {doorOpen=false;}
  // debugging
  //doorOpen=true;

  if ((millis()-start_time>LED_ANIMATIONS_DURATION)||!doorOpen){
    LED("off");
    if (doorOpen==true){Serial.print(" battery voltage: "); Serial.print(batteryVoltage);Serial.println("V");}
    delay(50);
    display1.init(115200); // enable diagnostic output on Serial

    if(batteryVoltage>2){
      displayDashboard(display1,updated_code_run_counter, updated_current_citation,number_of_citations, batteryVoltage);
      delay(2000);
    }
    drawBitmaps(display1);
    delay(2000);

    String citation;
    File myDataFile = SPIFFS.open(current_filename, "r");              // Open the file again, this time for reading
    if (!myDataFile) Serial.println("file open failed");  // Check for errors
    int entry=0;
    /*while (myDataFile.available()) {
      citation+=(char)myDataFile.read();                   // Read all the data from the file and save it into a string
    }*/
    //updated_current_citation=3;
    //int target_citation=updated_current_citation%number_of_citations;
    //Serial.println(number_of_citations);
    //Serial.println(updated_current_citation);
    int target_citation=updated_current_citation%number_of_citations;
    Serial.print("target_citation: ");Serial.println(target_citation);
    while (entry<target_citation){
      entry=entry+1;
      if(myDataFile.available()){citation=myDataFile.readStringUntil('\n');}
    }
    myDataFile.close();    // Close the file
    //citation="un été";
    //citation="Test message: Hâte-toi d'Être";
    // Substitute characters no part of 7 bit font with others that are less needed. Will be displayed properly using modified font.
    citation.replace("ô","#");
    citation.replace("É","$");
    citation.replace("û","*");
    citation.replace("ç","+");
    citation.replace("î","<");
    citation.replace("à","{");
    citation.replace("ê","|");
    citation.replace("é","}");
    citation.replace("è","~");
    citation.replace("ë",">");
    citation.replace("ù","^");
    citation.replace("ï","_");
    citation.replace("Ê","=");
    citation.replace("â","\\");


    citation=formatMessage(citation);  // Modify message to avoid breaking words at end of number_of_lines

    print_string(display1,citation);

    delay(500);
    display1.powerOff();

    Serial.println("Job done! Now starting deep sleep.");
    ESP.deepSleep(0);
  }
}

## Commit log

2021-03-10 First code with all main features working with V1 electronic circuit.
    [CroqueLivreSaintGerard2021_V1.sch]
2021-05-12 Project as per the day of first release into real world!
    [Assemblage_PCB_ecran.FCStd, Battery_Charging_Simulation.xlsx, Butée_V1.FCStd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]
2021-05-14 Fixed a first bug - Automatically delete jog.json files if they are found corrupted based on their size - Not most robust solution but project works again ;-)
    [Poignée_V1.FCStd]
